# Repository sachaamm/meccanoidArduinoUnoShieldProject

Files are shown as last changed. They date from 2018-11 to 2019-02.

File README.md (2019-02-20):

## Meccanoid Personnal Robot Arduino PROJECT

### Overview

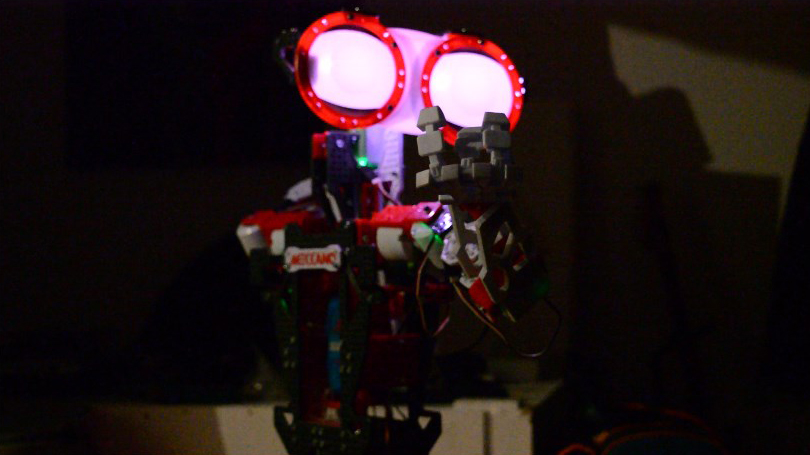
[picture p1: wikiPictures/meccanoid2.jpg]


https://www.youtube.com/watch?v=WydUIxD037A

### Hardware

This is the hardware used on this project
- Arduino Esplora controller ( [available here](https://fr.shopping.rakuten.com/offer/buy/2201571401/gratuit-esplora-rocker-game-board-atmega32u4-module-support-robot-ecran-lcd-1-8-pouces-tft.html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|pcrid|53434268603|pkw||pmt|&ja2=tsid:67590|cid:285670043|agid:14467128323|tid:aud-269143871707:pla-89152206803|crid:53434268603|nw:g|rnd:16272168161431935316|dvc:c|adp:1o1&gclid=Cj0KCQiAm5viBRD4ARIsADGUT25t6cqBpQwFY6DI_-hoSrfeVMcB9rYTRa3jL_OBDdxffjhCL8IMMwQaAhTVEALw_wcB) )
- 2x HM10 Bluetooth ( [available here](https://fr.shopping.rakuten.com/offer/buy/2552517283/bluetooth-4-0-pour-arduino-android-ios-hm-10-ble-cc2540-cc2541-serie-sans-fil-module.html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|pcrid|248309744840|pkw||pmt|&ja2=tsid:|cid:723021248|agid:58346345904|tid:aud-329787467942:pla-412904372812|crid:248309744840|nw:g|rnd:14070458870104494051|dvc:c|adp:1o1&gclid=Cj0KCQiAm5viBRD4ARIsADGUT24Wg6h3EPiis6JnYEjRWdm48go2qsXzKBhFZeI0HbhM2KkK3keFkXkaAp33EALw_wcB) )
- 2x Arduino UNO ( Eelego UNO ) ( [available here](https://fr.farnell.com/arduino-org/a000073/arduino-uno-cms-kit-de-dev/dp/2285200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|pcrid|80993927942|&CAWELAID=120185620000343524&CAGPSPN=pla&CAAGID=13038120062&CMP=KNC-GFR-GEN-SHOPPING-2285200&CATCI=aud-127173563342:pla-89203456717) )
- 1x FourRelay-5V module ( [available here](https://www.banggood.com/fr/5V-4-Channel-Relay-Module-For-Arduino-PIC-ARM-DSP-AVR-MSP430-Blue-p-87987.html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) )
- 1x FTDI Chip ( [available here](https://fr.banggood.com/FTDI-USB-OSD-Programmer-Module-for-F3-Flight-Control-AIO-Transmitter-OSD-BEC-Current-Sensor-p-1111287.html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) )
- 1x 5V supply for Arduino B
- Wires / connector  / etc...

### Installation 
- Install Meccanoid Arduino Library ( [provided on this link](http://www.meccano.com/meccanoid-opensource) )
- Set up your Bluetooth slave-master pairing with an FTDI chip. One device will be Master and the other will be slave.
( [check this link](https://www.instructables.com/id/How-to-Use-Bluetooth-40-HM10/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) )
- Upload the Arduino Source code on your devices, included in this repository in **Arduino/** 

   **EsploraBT3/** is for Esplora Controller
   
   **ReceiveBTEsplora_ArduinoRelay/** is for Arduino A
   
   **ReceiveBTESplora_Servos/** is for Arduino B
  
- Connect wires and devices following the schematic picture for your 2 Arduino and your HM10 device
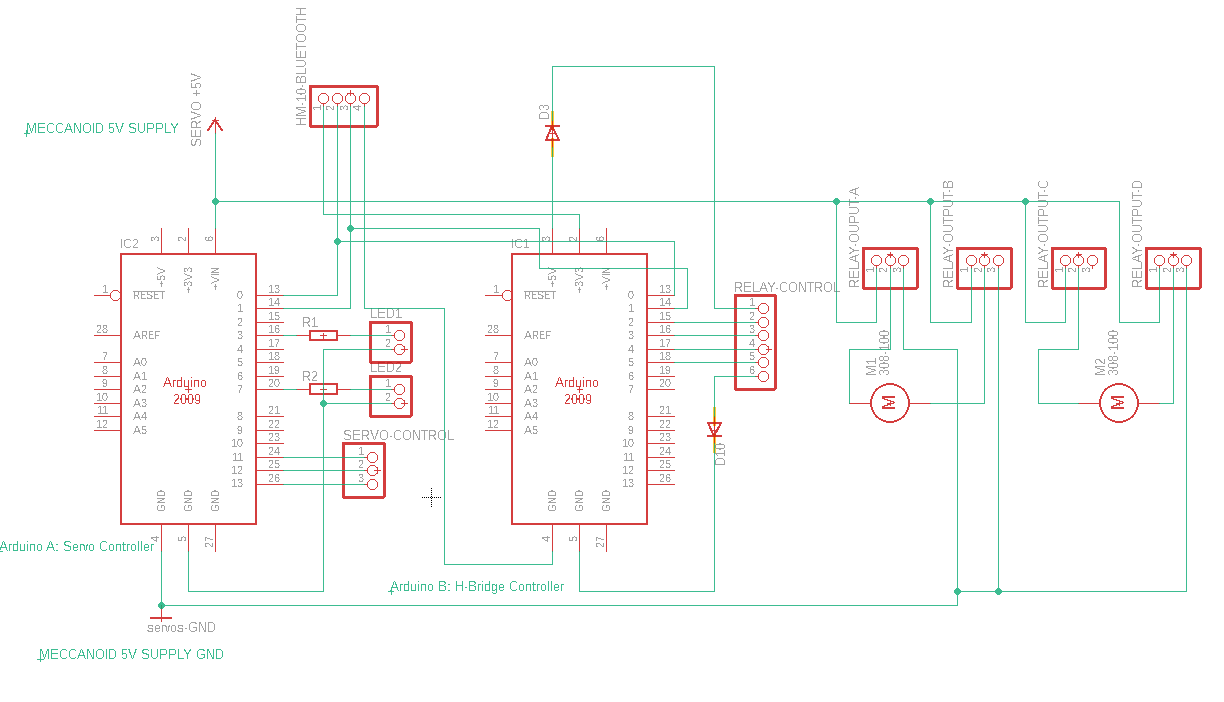
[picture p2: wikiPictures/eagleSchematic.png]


- Connect HM10 master bluetooth device to your Esplora controller following this picture 
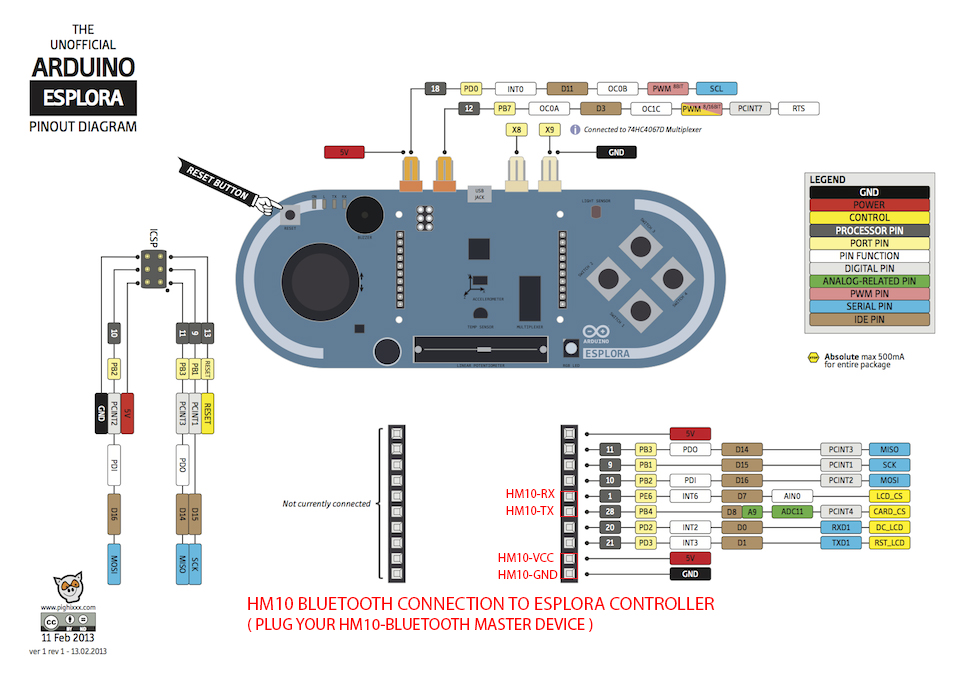
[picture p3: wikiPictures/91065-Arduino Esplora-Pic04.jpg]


### Instructions

- **Do not connect Meccanoid 5V supply GND to your Arduino B GND**, you will get a short-circuit on your HM10 bluetooth device which may destroy your device.
- **Do not upload your Arduino code when HM10-Serial connection is occuring** ( on the Arduino A, the HM10 device is connected to the Serial ports,
DIGITAL 0 (RX) and DIGITAL 1 (TX). 
- You may plug your motors to the HBridge in a different way than mine. If you get a mismatch on instructions directions, you can edit the Arduino B Code ( **ReceiveBTEsplora_ArduinoRelays** )
- Provide another 5V supply to your Arduino A using the USB port, because this device is controlling relays on a circuit supplied by the Meccanoid 5V supply, we have to supply this Arduino to another current source to avoid short circuits on the HBridge feet motors.

### Develop

- You can edit your own animations by editing the Arduino A Code ( **ReceiveBTEsplora_Servos** )

### STL Files

2 stl files for 3D printing are provided in order to grab easily your Esplora controller on hands

# Have Fun !

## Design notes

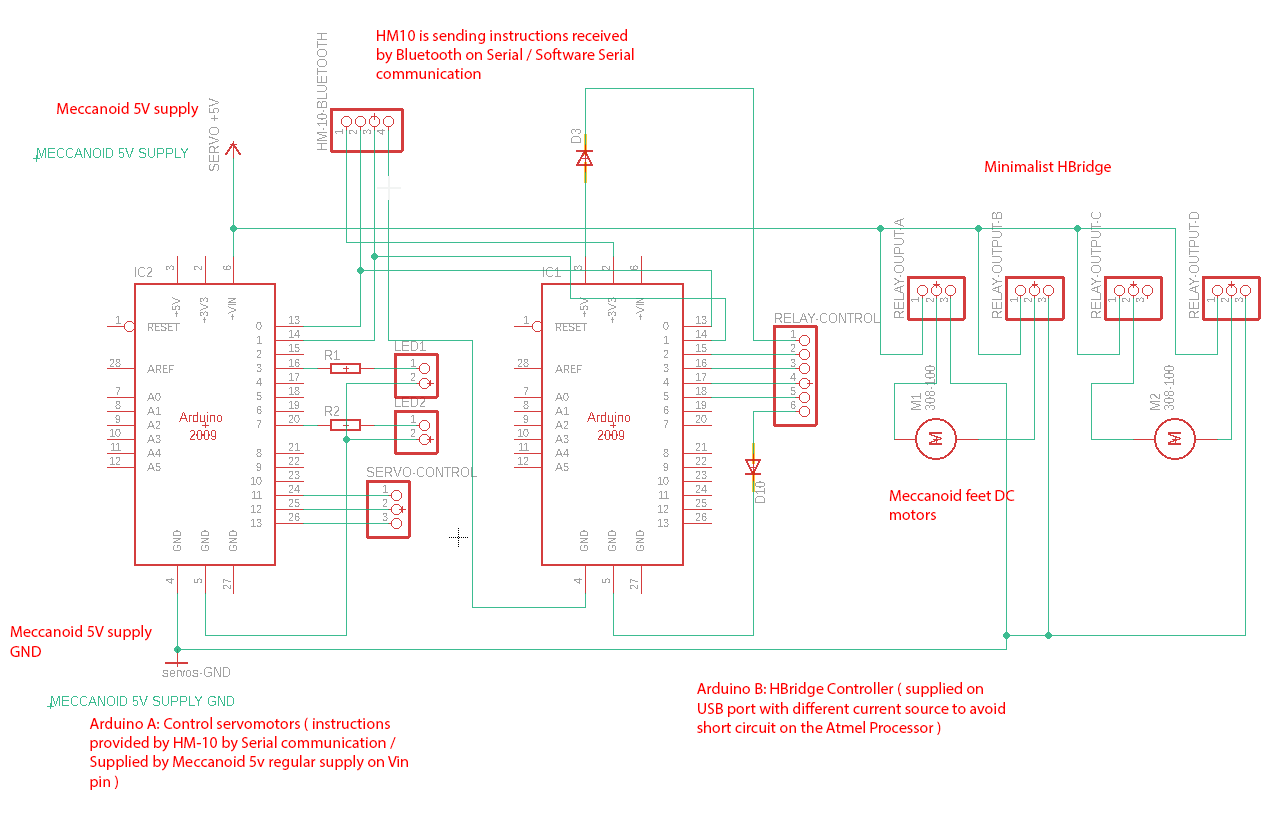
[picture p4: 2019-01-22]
wikiPictures/eagle_2019-01-22_17-27-2222.png

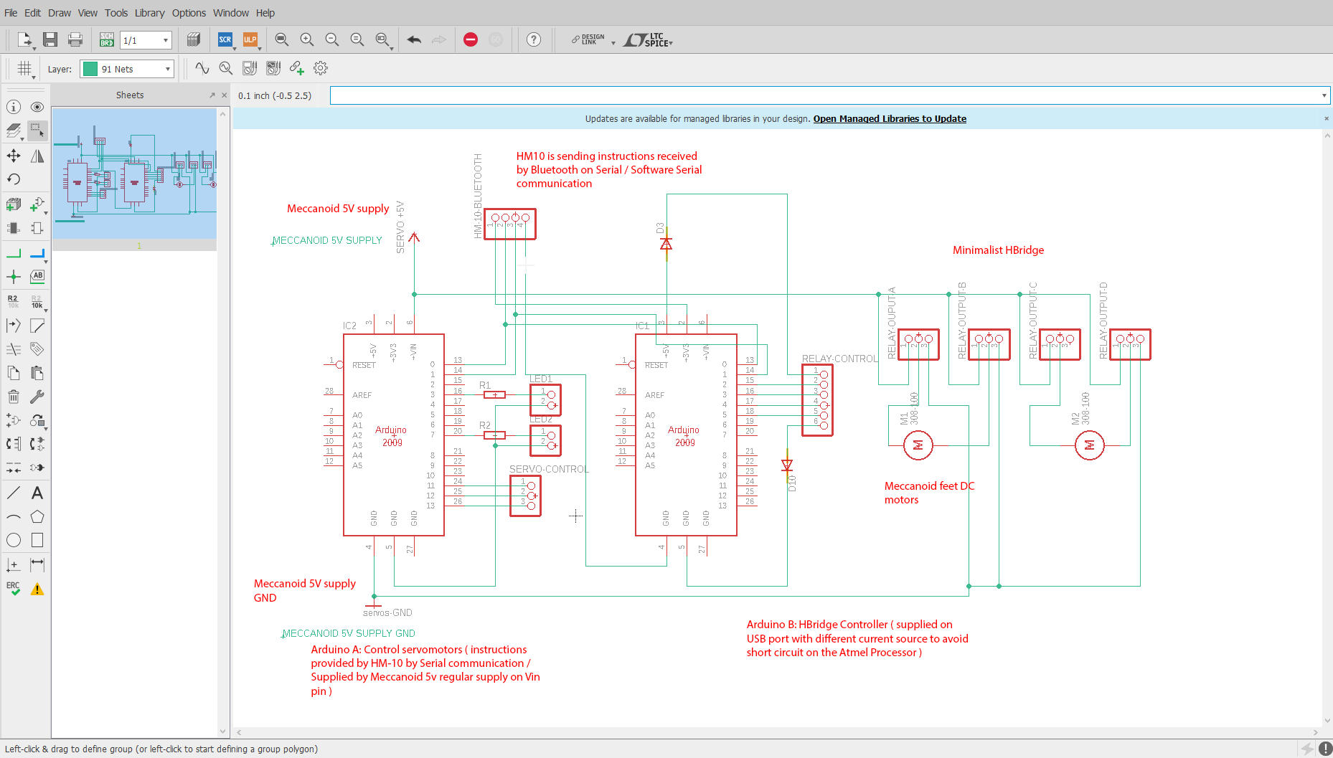
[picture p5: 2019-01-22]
wikiPictures/eagle_2019-01-22_17-27-22.png

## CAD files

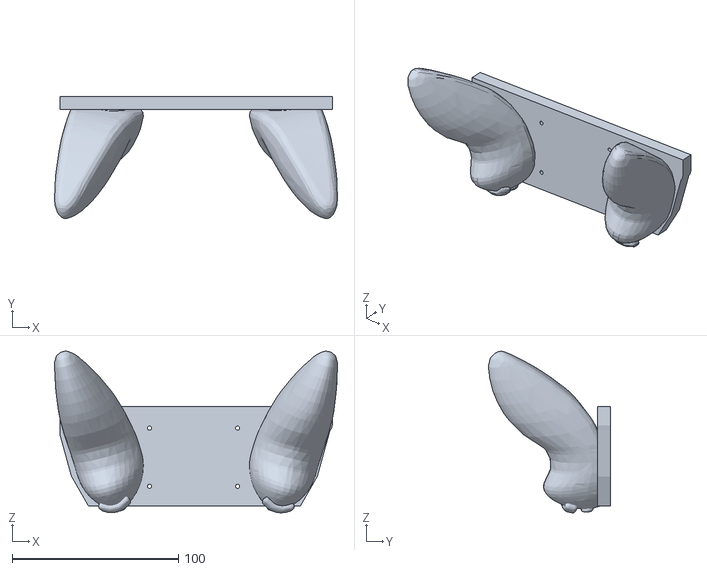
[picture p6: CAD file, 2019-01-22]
Esplora-STL/GameControllerV3-Body.stl
170.3 x 73.6 x 97.4

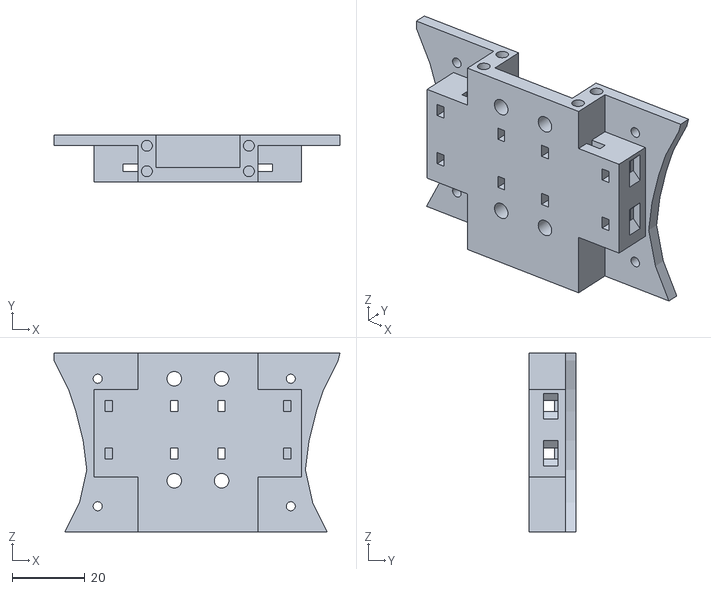
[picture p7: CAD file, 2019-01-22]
Esplora-STL/GameControllerV8-BluetoothCase.stl
78.5 x 13.0 x 49.0

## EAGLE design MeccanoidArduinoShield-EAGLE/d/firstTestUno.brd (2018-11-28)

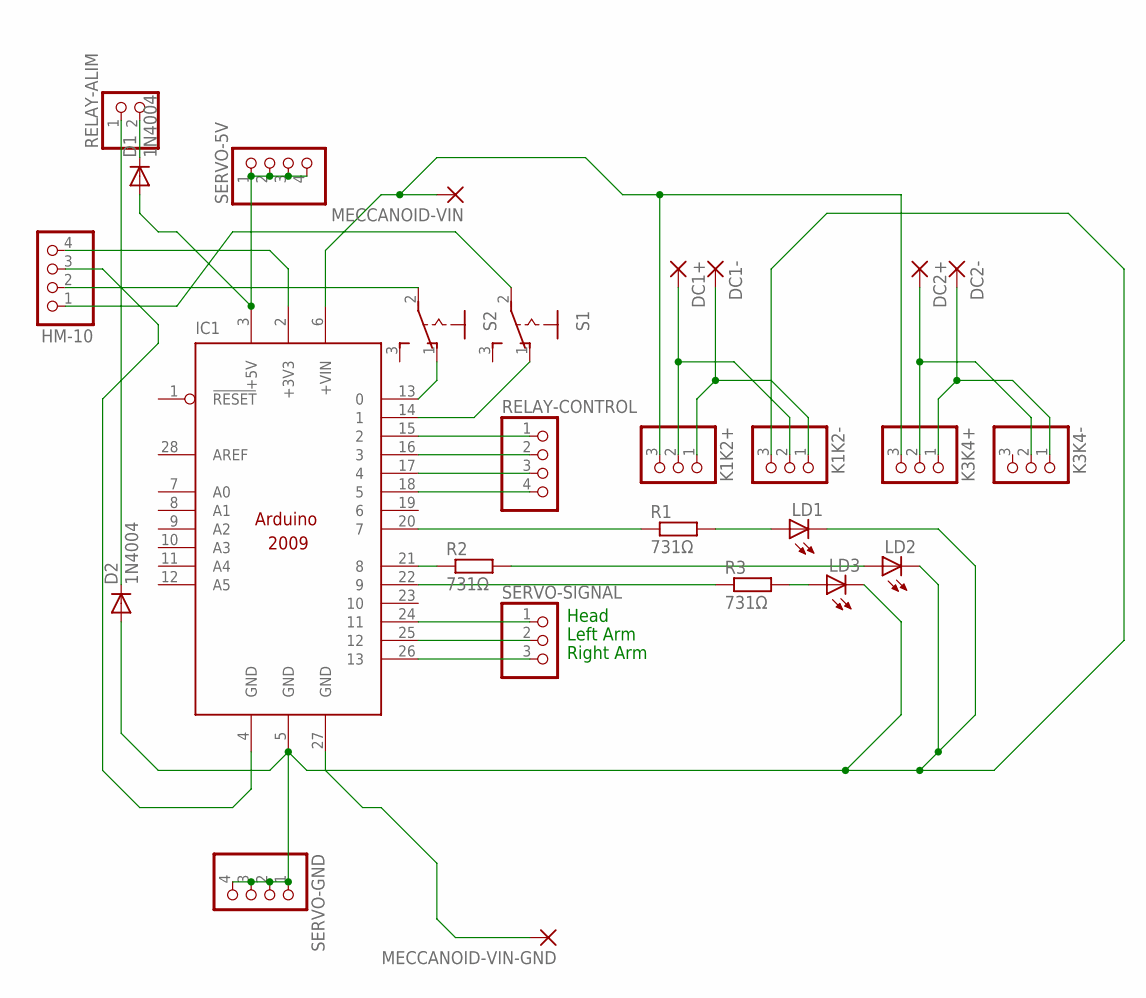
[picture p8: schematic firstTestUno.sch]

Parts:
D1, D2: 1N4004; DO41-10; MPN 1N4004+
DC1+, DC1-, DC2+, DC2-: 1,6/0,8; MPN TK20-1,6/0,8-PVDF-CL
HM-10: PINHD-1X4; 1X04
IC1: ARDUINO2009_10; ARDUINO2009
K1K2+, K1K2-, K3K4+, K3K4-: PINHD-1X3/90; 1X03/90
LD1, LD2, LD3: LED3MM; MPN LED 2F
MECCANOID-VIN: 1,6/0,8; MPN TK20-1,6/0,8-PVDF-CL
MECCANOID-VIN-GND: 1,6/0,8; MPN TK20-1,6/0,8-PVDF-CL
R1, R2, R3: 731Ω; 0207/5V; MPN 74270035
RELAY-ALIM: PINHD-1X2; 1X02; MPN B65659F0001X023
RELAY-CONTROL: PINHD-1X4; 1X04
S1, S2: 255SB; MPN CA3106E32-55SB03
SERVO-5V: PINHD-1X4; 1X04
SERVO-GND: PINHD-1X4; 1X04
SERVO-SIGNAL: PINHD-1X3; 1X03; MPN V23234A0001X038-EV-144

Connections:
unnamed: HM-10.3, IC1.4 (GND)
unnamed: HM-10.4, IC1.2 (+3V3)
unnamed: IC1.13 (0), S2.1 (O)
unnamed: D1.A, IC1.3 (+5V), SERVO-5V.1, SERVO-5V.2, SERVO-5V.3, SERVO-5V.4
unnamed: HM-10.2, S2.2
unnamed: D1.C, RELAY-ALIM.2
unnamed: IC1.27 (GND), MECCANOID-VIN-GND.1
unnamed: IC1.26 (13), SERVO-SIGNAL.3
unnamed: IC1.25 (12), SERVO-SIGNAL.2
unnamed: IC1.24 (11), SERVO-SIGNAL.1
unnamed: IC1.15 (2), RELAY-CONTROL.1
unnamed: IC1.16 (3), RELAY-CONTROL.2
unnamed: IC1.17 (4), RELAY-CONTROL.3
unnamed: IC1.18 (5), RELAY-CONTROL.4
unnamed: D2.C, RELAY-ALIM.1
unnamed: IC1.20 (7), R1.1
unnamed: DC1+.1, K1K2+.2, K1K2-.2
unnamed: IC1.14 (1), S1.1 (O)
unnamed: HM-10.1, S1.2
unnamed: LD1.A, R1.2
unnamed: DC1-.1, K1K2+.1, K1K2-.1
unnamed: LD2.A, R2.2
unnamed: LD3.A, R3.2
unnamed: IC1.22 (9), R3.1
unnamed: IC1.21 (8), R2.1
unnamed: DC2+.1, K3K4+.2, K3K4-.2
unnamed: DC2-.1, K3K4+.1, K3K4-.1
unnamed: IC1.6 (+VIN), K1K2+.3, K3K4+.3, MECCANOID-VIN.1
unnamed: D2.A, IC1.5 (GND), K1K2-.3, LD1.K (C), LD2.K (C), LD3.K (C), SERVO-GND.1, SERVO-GND.2, SERVO-GND.3, SERVO-GND.4

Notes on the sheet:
Left Arm
Right Arm
Head

Board: 2 copper layers, 27 parts (0 on the bottom side), 29 nets, no tracks yet.

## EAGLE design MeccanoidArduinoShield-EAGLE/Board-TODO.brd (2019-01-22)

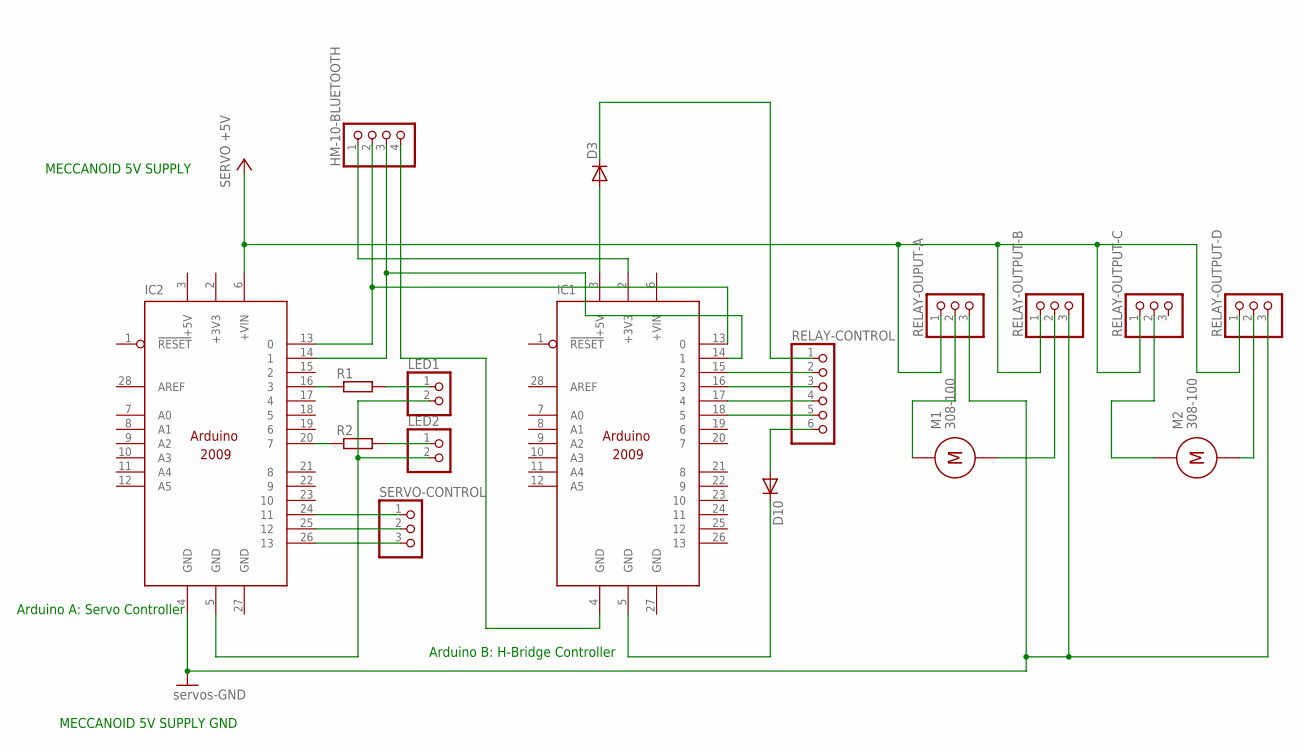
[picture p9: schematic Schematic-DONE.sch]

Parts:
D3, D10: 1N4148DO35-7; DO35-7
HM-10-BLUETOOTH: PINHD-1X4; 1X04
IC1, IC2: ARDUINO2009_10; ARDUINO2009
LED1, LED2: PINHD-1X2; 1X02
M1, M2: 308-100
R1, R2: R-EU_0204/2V; 0204V
RELAY-CONTROL: PINHD-1X6; 1X06
RELAY-OUPUT-A: PINHD-1X3; 1X03
RELAY-OUTPUT-B: PINHD-1X3; 1X03
RELAY-OUTPUT-C: PINHD-1X3; 1X03
RELAY-OUTPUT-D: PINHD-1X3; 1X03
SERVO-CONTROL: PINHD-1X3; 1X03

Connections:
+3V3: IC2.2 (+3V3)
+5V: IC2.3 (+5V), IC2.6 (+VIN), RELAY-OUPUT-A.1, RELAY-OUTPUT-B.1, RELAY-OUTPUT-C.1, RELAY-OUTPUT-D.1; also elsewhere on the board
GND: IC1.27 (GND), IC2.4 (GND), IC2.27 (GND), RELAY-OUPUT-A.3, RELAY-OUTPUT-B.3, RELAY-OUTPUT-D.3
unnamed: M1.POS, RELAY-OUPUT-A.2
unnamed: M2.POS, RELAY-OUTPUT-C.2
unnamed: D3.C, RELAY-CONTROL.1
unnamed: IC1.15 (2), RELAY-CONTROL.2
unnamed: IC1.16 (3), RELAY-CONTROL.3
unnamed: IC1.17 (4), RELAY-CONTROL.4
unnamed: IC1.18 (5), RELAY-CONTROL.5
unnamed: D3.A, IC1.3 (+5V)
unnamed: IC2.16 (3), R1.1
unnamed: M1.NEG, RELAY-OUTPUT-B.2
unnamed: IC2.24 (11), SERVO-CONTROL.1
unnamed: D10.C, IC1.5 (GND)
unnamed: IC2.25 (12), SERVO-CONTROL.2
unnamed: IC2.26 (13), SERVO-CONTROL.3
unnamed: HM-10-BLUETOOTH.1, IC1.2 (+3V3)
unnamed: D10.A, RELAY-CONTROL.6
unnamed: HM-10-BLUETOOTH.2, IC1.13 (0), IC2.13 (0)
unnamed: HM-10-BLUETOOTH.4, IC1.4 (GND)
unnamed: HM-10-BLUETOOTH.3, IC1.14 (1), IC2.14 (1)
unnamed: LED1.1, R1.2
unnamed: IC2.5 (GND), LED1.2, LED2.2
unnamed: LED2.1, R2.2
unnamed: IC2.20 (7), R2.1
RELAY-OUTPUT-D: M2.NEG, RELAY-OUTPUT-D.2

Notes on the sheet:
MECCANOID 5V SUPPLY
MECCANOID 5V SUPPLY GND
Arduino A: Servo Controller
Arduino B: H-Bridge Controller

Board: 2 copper layers, 18 parts (0 on the bottom side), 26 nets, no tracks yet.

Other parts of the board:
D1: DO35-7

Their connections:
+5V: D1.A, D1.C; also elsewhere on the board

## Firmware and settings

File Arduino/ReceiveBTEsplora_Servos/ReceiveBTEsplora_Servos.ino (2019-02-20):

// The code to upload on Arduino A - the arm/head Servomotors controller 
#include "MeccaBrain.h"

MeccaBrain head(11); // VIOLET
MeccaBrain leftArm(12); // GRIS
MeccaBrain rightArm(13); // BLEU

int pwmSpeed = 255;



// COMMUNICATION PATTERNS
byte startPatternByte = 'a';
byte endPatternByte = 'z';

// COMMUNICATION
int startByteIndex = 0;
int endByteIndex = 0;
int messageByteIndex = 0;

int checkReceiveSerial = 0;
int checkReceiveSerialLimit = 50;

bool messageIsReady = false;
bool messageIsOver = false;
int bytesExpected = 4; // direction / animation / slider_state / speed
bool debugMessageProcess = false;

//RELAY
int relayPinA = 2;
int relayPinB = 3;
int relayPinC = 4;
int relayPinD = 5;
bool debugRelay = false;


// ANIMATION
bool playAnimation = false;
int buttonState = 0;
int sliderState = 0; // Slider state is defining animation state
//byte buttonState = 'x';
int animationCycle = 500;
int frameIndex = 0;

// LEDS
int led = 13;
int ledState = HIGH;

// DEBUG LEDs
int redLed = A0;
int greenLed = 8;
int yellowLed = 9;


// %ECCA MOVE : a simple keyframe servoPos interpolation
struct MeccaMove{
  
  byte leftArmAPosition[8];
  byte leftArmBPosition[8];
  byte leftArmCPosition[8];
  byte rightArmAPosition[8];
  byte rightArmBPosition[8];
  byte rightArmCPosition[8];

  byte headAPosition[8];
  byte headBPosition[8];

  byte headColor[4];
};

MeccaMove animations[12] = {

  // TALK : NON EXPRESSIVE . YELLOW
 {
    { 0 , 0, 0 ,0 , 0, 0, 0 , 0 }, // leftA
    { 220 , 220 , 220 , 220, 220 , 220 , 220 , 220 }, // leftB
    { 0 , 10 , 20 , 0 , 20, 0 , 40 , 0} , // leftC
    { 0 , 0 , 0 , 0, 0, 0, 0 ,0 }, // rightA
    { 220 , 220 , 220, 220, 220, 220 , 220 , 220 }, // rightB
    { 220 , 230 , 220, 200,220 , 180 ,210 , 220}, // rightC
    { 120 , 120 , 120 , 120, 120 ,120 ,120,120 }, // hA
    { 120 , 120 , 120 , 120 , 120 , 130 , 20 , 20},  // hB
    { 0 , 0 , 0 , 0 }  
  },

  // 1b TALK 2 : EXPRESSIVE   YELLOW
  {
    { 20 , 10, 0 ,20 , 0, 0, 0 , 0 },
    { 230 , 220 , 220 , 220, 220 , 220 , 220 , 220 }, 
    { 0 , 10 , 20 , 0 , 20, 0 , 40 , 0}, 
    { 0 , 20 , 10 , 0, 20, 0, 0 ,0 }, 
    { 220 , 220 , 220, 220, 220, 220 , 220 , 220 }, 
    { 220 , 230 , 220, 200,220 , 180 ,210 , 220}, 
    { 120 , 110 , 120 , 120, 220 ,120 ,120,120 }, 
    { 120 , 120 , 120 , 120 , 120 , 130 , 20 , 20},
    { 3 , 3 , 3 , 2 }  
  },


  // 1c TALK 3 : WORRIED   YELLOW
  {
    { 20 , 10, 50 ,20 , 0, 40, 30 , 0 }, 
    { 230 , 180 , 220 , 220, 220 , 180 , 220 , 220 }, 
    { 0 , 10 , 20 , 0 , 20, 0 , 40 , 0}, 
    { 0 , 20 , 10 , 0, 20, 0, 0 ,0 }, 
    { 220 , 170 , 220, 220, 180, 220 , 220 , 220 }, 
    { 220 , 230 , 220, 200,220 , 180 ,210 , 220}, 
    { 120 , 110 , 140 , 120, 220 ,120 ,20,120 }, 
    { 120 , 120 , 120 , 180 , 120 , 130 , 110 , 110},
    { 4 , 4 , 4 , 4 }  
  },

  // 2a EXPLAIN STH BLUE
  {
    { 20 , 10, 50 ,20 , 60, 40, 30 , 0 }, // headA
    { 230 , 180 , 220 , 220, 220 , 180 , 220 , 220 }, // headB
    { 0 , 10 , 20 , 0 , 20, 0 , 40 , 0}, // lArmA
    { 40 , 20 , 10 , 0, 20, 60, 0 ,0 }, // lArmB
    { 180 , 170 , 180, 180, 180, 220 , 220 , 220 }, // lArmC
    { 220 , 230 , 220, 200,220 , 180 ,210 , 220}, // rArmA
    { 120 , 120 , 120 , 120, 120 ,120 ,120,120 }, // rArmB
    { 120 , 120 , 120 , 120 , 120 , 120 , 120 , 120},  // rArmC
    {3,2,7,6}
  },

  // 2b : SAY HELLO   BLUE
  {
    { 80 , 80, 80 ,80 , 80, 80, 80 , 60 },
    { 120 , 120 , 120 , 120, 120 , 120 , 120 , 220 },
    { 0 , 10 , 20 , 0 , 20, 0 , 40 , 0},
    { 100 , 100 , 100 , 100, 100, 100, 100 ,100 },
    { 120 , 120 , 120, 120, 120, 120 , 120 , 220 },
    { 220 , 230 , 220, 200,220 , 180 ,210 , 220},
    { 120 , 120 , 120 , 120, 120 ,120 ,120,120 },
    { 120 , 120 , 120 , 120 , 120 , 120 , 120 , 120},
    {7,3,7,3}
  },

  // 2c : DANCE : HEADBANG     BLUE
  {
    { 180 , 80, 80 ,80 , 80, 80, 80 , 60 },
    { 120 , 120 , 120 , 120, 120 , 120 , 120 , 220 },
    { 0 , 10 , 20 , 0 , 20, 0 , 40 , 0},
    { 10 , 10 , 180 , 10, 100, 100, 100 ,100 },
    { 120 , 120 , 120, 120, 120, 120 , 120 , 220 },
    { 220 , 230 , 220, 200,220 , 180 ,210 , 220},
    { 120 , 120 , 220 , 120, 120 ,120 ,120,120 },
    { 120 , 20 , 120 , 120 , 20 , 120 , 120 , 120},
    {0,0,0,0}
  },

  // 3a : ERROR SYSTEM !   GREEN
  {
    { 10 , 20, 10 ,10 , 20, 10, 80 , 60 },
    { 220 , 120 , 220 , 210, 120 , 220 , 120 , 220 },
    { 0 , 10 , 20 , 66 , 20, 66 , 40 , 0},
    { 10 , 10 , 66 , 10, 100, 100, 100 ,100 },
    { 120 , 66 , 120, 120, 66, 120 , 120 , 220 },
    { 220 , 230 , 66, 200,220 , 66 ,210 , 220},
    { 120 , 120 , 66 , 66, 66 ,66 ,120,120 },
    { 120 , 20 , 66 , 66 , 66 , 120 , 120 , 120},
    { 7,0,0,2}
  },

  // 3b : CONDUCTOR     GREEN
  {
    { 10 , 10, 10 ,10 , 20, 10, 10 , 60 },
    { 66 , 66 , 66 , 66, 66, 66 , 66 , 66 },
    { 66, 66 , 66 , 66 , 66, 66 , 66, 66},
    { 10 , 10 , 66 , 10, 100, 100, 100 ,100 },
    { 120 , 66 , 120, 120, 66, 120 , 120 , 220 },
    { 220 , 230 , 66, 200,220 , 66 ,210 , 220},
    { 120 , 120 , 66 , 66, 66 ,66 ,120,120 },
    { 120 , 20 , 66 , 66 , 66 , 120 , 120 , 120},
    { 4,4,3,2}
  },

  // 3c : EXPLAINER      GREEN
  {
    { 1 , 2, 3 ,4 , 5, 10, 10 , 60 },
    { 1 , 2 , 10 , 20, 66, 66 , 66 , 66 },
    { 20, 66 , 66 , 20 , 66, 66 , 66, 66},
    { 10 , 10 , 10 , 10, 10, 10, 10 ,100 },
    { 120 , 66 , 66, 66, 66, 66 , 66 , 66 },
    { 220 , 230 , 220, 200,220 , 200 ,210 , 220},
    { 120 , 120 , 120 , 120, 120 ,120 ,120,120 },
    { 120 , 120, 120 , 120 , 120 , 120 , 120 , 120},
    { 5,3,2,4}
  },

  // 4a HEAD ONLY    RED
  {
    { 100 , 100, 100,100 , 100, 100, 100 , 100 },
    { 100 , 100 , 100 , 100, 100, 100 , 100 , 100 },
    { 100 , 100 , 100 , 100, 100, 100 , 100 , 100 },
    { 100 , 100 , 100 , 100, 100, 100 , 100 , 100 },
    { 100 , 100 , 100 , 100, 100, 100 , 100 , 100 },
    { 100 , 100 , 100 , 100, 100, 100 , 100 , 100 },
    { 50 , 120 , 120 , 220, 120 ,120 ,120,120 },
    { 120 , 120, 120 , 150 , 150 , 120 , 120 , 120},
    { 6,3,4,5  }
  },

  // 4b WARM UP     RED
  {
    { 100 , 100, 100,100 , 100, 10, 100 , 100 },
    { 100 , 100 , 10 , 100, 100, 100 , 100 , 100 },
    { 100, 100 , 100 , 100 , 100, 100 , 100, 100},
    { 100 , 100 , 100 , 10, 100, 100, 100 ,100 },
    { 100 , 10, 100, 100, 100, 100 , 100 , 100 },
    { 100 , 100 , 100, 100,100 , 100 ,100 , 100},
    { 50 , 50 , 50 , 50, 50 ,50 ,50,50 },
    { 50 , 50, 50 , 50 , 50 , 50 , 50 , 50 },
    { 6,1,1,1 }
  },

  // 4c REQUIRE     RED
  {
    { 200 , 200, 200,200 , 200, 200, 200 , 200 },
    { 100 , 210 , 110 , 100, 100, 100 , 100 , 100 },
    { 200, 200 , 200 , 230 , 230, 230 ,200, 200},
    { 0 , 0 , 0 , 0, 0, 0, 0 ,0 },
    { 220 , 220, 220, 222, 220, 220 , 230 , 200 },
    { 230 , 200 , 230, 160,200 , 200 ,200 , 200},
    { 150 , 130 , 150 , 150, 130 ,150 ,150,150 },
    { 150 , 150, 130 , 150 , 150 , 130 , 150 , 150 },
    { 7,7,7,7}
  }
};



int cycleValueMax = 6; 
int cycleValue = 0; 


      

void setup() {

  // Serial is getting data from bt- HM10
  Serial.begin(9600);

  // Relay pin to OUTPUT
  pinMode(relayPinA, OUTPUT);
  pinMode(relayPinB, OUTPUT);
  pinMode(relayPinC, OUTPUT);
  pinMode(relayPinD, OUTPUT);

  //LEDS to OUTPUT
  pinMode(redLed,OUTPUT);
  pinMode(greenLed,OUTPUT);
  pinMode(yellowLed,OUTPUT);

  pinMode(led,OUTPUT);

  //DEFAULT POSITION
  relayIdle();

}



void loop() {


    
    // use positions variables to set servp positions
   if(playAnimation){

      if( millis() % animationCycle == 0 && cycleValue < cycleValueMax){ 
        
        int animationIndex = (sliderState * 3 + buttonState); // 0 0 : 0 / 1 / 2 

        MeccaMove mm = animations[animationIndex];
        
        int lA = mm.leftArmAPosition[frameIndex % (sizeof(mm.leftArmAPosition)/2) ];
        int lB = mm.leftArmBPosition[frameIndex % (sizeof(mm.leftArmBPosition)/2) ];
        int lC = mm.leftArmCPosition[frameIndex % (sizeof(mm.leftArmCPosition)/2) ];
        int rA = mm.rightArmAPosition[frameIndex % (sizeof(mm.rightArmAPosition)/2) ];
        int rB = mm.rightArmBPosition[frameIndex % (sizeof(mm.rightArmBPosition)/2) ];
        int rC = mm.rightArmCPosition[frameIndex % (sizeof(mm.rightArmCPosition)/2) ];
    
        int hA = mm.headAPosition[frameIndex % (sizeof(mm.headAPosition)/2)];
        int hB = mm.headBPosition[frameIndex % (sizeof(mm.headBPosition)/2)];


        byte r = mm.headColor[0];
        byte g = mm.headColor[1];
        byte b = mm.headColor[2];
        byte d = mm.headColor[3];
        
        
        updateServoPosition(&leftArm,lA,lB,lC);
        updateServoPosition(&rightArm,rA,rB,rC);
        updateHeadServoPosition(&head,hA,hB,r,g,b,d);

      
        frameIndex++;
        cycleValue++;
        
      }
      //digitalWrite(yellowLed,HIGH);
      
    }else{
    
      resetServo();
      //digitalWrite(yellowLed,LOW);
  
  }

  checkReceiveSerial++;
  if(checkReceiveSerial > checkReceiveSerialLimit){
    digitalWrite(redLed,LOW); // HM 10 IS NOT ANYMORE RECEIVING
  }

  while (Serial.available()) {

      checkReceiveSerial = 0;

      digitalWrite(led,HIGH); // RED LIGHT IS TELLING US THAT WE ARE RECEIVING SERIAL

      analogWrite(redLed,255); // RED LIGHT IS TELLING US THAT WE ARE RECEIVING SERIAL

      byte b  = Serial.read();
      char c = (char)b;

      // READ BT MESSAGE PROCESS
      if(!messageIsReady && b == startPatternByte){
        messageIsReady = true;
        return;  
      }

      if(messageIsReady){

          if(messageByteIndex < bytesExpected){
          
            readBTInstructions(messageByteIndex,c); // READ BT DATA INSTRUCTIONS
            messageByteIndex++;
            
          }else{
            
            if(b == endPatternByte){
              messageIsReady = false;
              messageByteIndex = 0;
            }
            
          }
        
      }
      
  }


}

void readBTInstructions(int messageIndex,char c){

  if(messageIndex == 0){
    /*
    // READ DIRECTION VALUE
    digitalWrite(greenLed,LOW); 
    
    if( c == 'l' )  {
      relayTurnClockwise();
      //relayMoveForward();
      playAnimation = false;
      resetServo();
    }
    if( c == 'r' ){
      relayTurnCounterClockwise();
      //relayMoveBackward();
      playAnimation = false;
      resetServo();
    }
    if( c == 'd' ){
      relayMoveForward();
      //relayMoveBackward();
      //relayTurnClockwise();
      playAnimation = false;
      resetServo();
    }
    if( c == 'u' ){
      relayMoveBackward();
      //relayMoveForward();
      //relayTurnCounterClockwise();
      playAnimation = false;
      resetServo();
    }
    if( c == 'x' ){
      relayIdle();
      digitalWrite(yellowLed,HIGH);
    }
    */

  }

  if(messageIndex == 1){
    // READ BUTTONS VALUE
   
     

    cycleValue = 0;

    if( c == 'x' ){
  
    }

    if( c == '1' || c == '2' || c == '3' ){
      playAnimation = true;
      //animateMecca(sliderState,c);

      //buttonState = c;

    }

    if( c == '1') buttonState = 0;
    if( c == '2') buttonState = 1;
    if( c == '3') buttonState = 2;
    if( c == '4') {
      resetServo();
      playAnimation = false;
      relayIdle();
    }
      
  }

  if(messageIndex == 2){

    sliderState = c;

    if(buttonState == '1' || buttonState == '2' || buttonState == '3' ){
        playAnimation = true;
        //animateMecca(c,buttonState);
    }

    if(buttonState == '4'){
      //relayIdle();
    }

    if(c == 3){
      digitalWrite(greenLed,HIGH);
    }
    //digitalWrite(greenLed,HIGH);
 
  }

  
}

void resetServo(){

   head.setServotoLIM(0);
   head.setServotoLIM(1);
   
   leftArm.setServotoLIM(0);
   leftArm.setServotoLIM(1);
   leftArm.setServotoLIM(2);

   rightArm.setServotoLIM(0);
   rightArm.setServotoLIM(1);
   rightArm.setServotoLIM(2);

}


//////////////////
// RELAY
//////////////////

void relayIdle(){

   // IDLE
   digitalWrite(relayPinA, LOW);
   digitalWrite(relayPinB, LOW);
   digitalWrite(relayPinC, LOW);
   digitalWrite(relayPinD, LOW);

}

void relayTurnClockwise(){

    // LEFT
   digitalWrite(relayPinA,HIGH); 
   digitalWrite(relayPinB,LOW);
   digitalWrite(relayPinC,LOW);
   digitalWrite(relayPinD,HIGH);
   
}


void relayTurnCounterClockwise(){

   // RIGHT
   digitalWrite(relayPinA,LOW);
   digitalWrite(relayPinB,HIGH);
    digitalWrite(relayPinC,HIGH);
   digitalWrite(relayPinD,LOW); 
    
}


void relayMoveForward(){

   // FORWARD
   digitalWrite(relayPinA,LOW);
   digitalWrite(relayPinB,HIGH);
   digitalWrite(relayPinC,LOW);
   digitalWrite(relayPinD,HIGH);

}


void relayMoveBackward(){
      
   // BACKWARD
   digitalWrite(relayPinA,HIGH);
   digitalWrite(relayPinB,LOW);
   digitalWrite(relayPinC,HIGH);
   digitalWrite(relayPinD,LOW);

}


void updateServoPosition(MeccaBrain *s,int a, int b, int c){

    s->communicate();
    s->setServoPosition(0,a);
    s->setServoPosition(1,b);
    s->setServoPosition(2,c);

 }

void updateHeadServoPosition(MeccaBrain *h,int a, int b, byte r,byte g ,byte bb, byte d){

    h->communicate();
    h->setServoPosition(0,a);
    h->setServoPosition(1,b);
    h->setLEDColor(r,g,bb,d);

}

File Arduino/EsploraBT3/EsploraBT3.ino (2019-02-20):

// The code to upload on your Esplora controller

#include <SoftwareSerial.h> 
#include <Esplora.h> 

int hm10Tx = 8;  // TX-O pin of hm10 mate, Arduino D8
int hm10Rx = 7;  // RX-I pin of hm10 mate, Arduino D7

SoftwareSerial hm10(hm10Tx, hm10Rx);

int thresholdJoystick = 20;



// 
byte startPatternByte = 'a';
byte endPatternByte = 'z';

char directionJoystick = 'x'; // default = idle // l : LEFT / r : RIGHT / u : UP / d : DOWN
char buttonValue = 'x'; // default = none // 1 : UP / 2 : LEFT / 3 : RIGHT / 4 : DOWN

int sliderState = 0;

int speedValue = 0;


void setup()
{
  Serial.begin(9600);  // Begin the serial monitor at 9600bps

  hm10.begin(115200);  // The Bluetooth Mate defaults to 115200bps
  hm10.print("$");  // Print three times individually
  hm10.print("$");
  hm10.print("$");  // Enter command mode
  delay(100);  // Short delay, wait for the Mate to send back CMD
  hm10.println("U,9600,N");  // Temporarily Change the baudrate to 9600, no parity
  // 115200 can be too fast at times for NewSoftSerial to relay the data reliably
  hm10.begin(9600);  // Start hm10 serial at 9600

  buttonValue = 'x'; // default : none
  
}

void loop()
{
  
  int buttonDown = Esplora.readButton(SWITCH_DOWN);
  int buttonUp = Esplora.readButton(SWITCH_UP);
  int buttonLeft = Esplora.readButton(SWITCH_LEFT);
  int buttonRight = Esplora.readButton(SWITCH_RIGHT);

  directionJoystick = 'x'; // default = idle 
  buttonValue = 'x'; // default : none
  

  ///////////////////////////////////
  // READ SENSORS VALUES 
  ///////////////////////////////////
  
  // JOYSTICK
  int xValue = Esplora.readJoystickX();        // read the joystick's X position
  int yValue = Esplora.readJoystickY();        // read the joystick's Y position

   // BUTTONS
  readButtonState(buttonUp,SWITCH_UP,'1');
  readButtonState(buttonLeft,SWITCH_LEFT,'2');
  readButtonState(buttonRight,SWITCH_RIGHT,'3');
  readButtonState(buttonDown,SWITCH_DOWN,'4');


  if(xValue > thresholdJoystick && xValue > yValue){
    directionJoystick = 'l'; // MOVE TO LEFT
    Serial.println("xVal");
    Serial.println(xValue);

    speedValue = map(abs(xValue),thresholdJoystick,512,0,255);

    Serial.println(speedValue);
    
  }
  if(xValue < -thresholdJoystick && xValue < yValue) {
    directionJoystick = 'r'; // MOVE TO RIGHT
    Serial.println("xVal");
    Serial.println(xValue);

    speedValue = map(abs(xValue),thresholdJoystick,512,0,255);

    Serial.println(speedValue);
    
  }
  if(yValue > thresholdJoystick && yValue > xValue){
    directionJoystick = 'd'; // MOVE BACKWARD
    Serial.println("yVal");
    Serial.println(yValue);

    speedValue = map(abs(yValue),thresholdJoystick,512,0,255);

    Serial.println(speedValue);
    
  }
  if(yValue < -thresholdJoystick && yValue < xValue){
    directionJoystick = 'u'; // MOVE FORWARD
    Serial.println("yVal");
    Serial.println(yValue);

    speedValue = map(abs(yValue),thresholdJoystick,512,0,255);

    Serial.println(speedValue);
  }

  if(directionJoystick != 'x'){
    
    //buttonValue = 'x'; // ON REMET A ZERO buttonValue uniquement quand on recoit une direction de deplacement, ce qui permet de sauvegarder buttonValue quand le robot ne bouge pas

    
  }

  Serial.println(directionJoystick);
  
  sliderState = Esplora.readSlider() / 256; // 4 ANIMATION STATES 

  switch(sliderState){

    case 3:
    Esplora.writeRGB(255, 0, 0);  // make the LED red   
    break;

    case 2:
    Esplora.writeRGB(0, 255, 0);  // make the LED green  
    break;

    case 1:
    Esplora.writeRGB(0, 0, 255);  // make the LED blue  
    break;

    case 0:
    Esplora.writeRGB(255, 255, 0); // make the LED yellow
    break;

    default:
    Esplora.writeRGB(255, 0, 0);  // make the LED red
    break;  
    
  }

  /////////////////////////////
  // DEFINE MESSAGE
  /////////////////////////////
  sendBTMessage();

  

  
  
 //delay(50);
  

  
  

  
}

////////////////////////////
// COMMUNICATION
////////////////////////////

void sendBTMessage(){

  //sendStartPattern();
  hm10.write(startPatternByte);
  hm10.write(directionJoystick);
  hm10.write(buttonValue);
  hm10.write(sliderState);
  hm10.write(speedValue);
  hm10.write(endPatternByte);
  //sendEndPattern();

}

/*
void sendStartPattern(){

  for(int i = 0 ; i < sizeof(startPattern) ; i++){
    hm10.write(startPattern[i]);   
  }

}

void sendEndPattern(){

  for(int i = 0 ; i < sizeof(endPattern) ; i++){
    hm10.write(endPattern[i]);    
  }

}
*/


void readButtonState(int button, int argument,char message){

  if(button == LOW)  // If button is pressed
  {
    // Send message to hm10
    //hm10.print(message);
    buttonValue = message;
    
    
    while(button == LOW){ 
      button = Esplora.readButton(argument);
      
    } // Assures message is only sent once.
    
  }

}

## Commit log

2018-11-28 Add content
    [firstTestUno.brd, firstTestUno.sch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]
2019-01-11 based on L293D chip
    [firstTestUno.brd, firstTestUno.sch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]
2019-01-22 Update content for youtube video
    [Board-TODO.brd, Schematic-DONE.sch, firstTestUno.brd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]
2019-02-20 Meccanoid v3 : pwm hbridge with npn
